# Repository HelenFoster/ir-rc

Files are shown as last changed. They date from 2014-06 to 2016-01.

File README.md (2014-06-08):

Infrared remote control experiments
=====

The aim is to have a tiny transmitter which works with the OpenPandora without compromising on its handheld quality. (For receivers, this is not a problem, because they are generally resting on a solid surface while you send them signals from somewhere else. But for a transmitter, handheld is very useful!)

Currently using very simple descriptions of the waveforms (and two different waveforms per code for the protocols with a toggle bit). Later it would be useful to handle the actual protocols, e.g. integrate with LIRC.

Licensing
----
C code: MIT License (see code headers)
Schematic and PCB files: CC BY-SA http://creativecommons.org/licenses/by-sa/4.0/

rx_dur (Arduino)
----
Monitors a digital signal on the specified pin, waits for this signal to match the trigger level, and outputs a list of comma-separate durations (in microseconds) on Serial. The first duration is the length of time the signal stays at the trigger level; the second is the length of time it stays at the opposite level after that; and so on. It records data until the buffer is full or until the specified maximum time after the trigger, then it transmits on Serial afterwards.

This can be connected to an IR demodulator device to read remote control signals.

tx_tone (Arduino)
----
Reads a comma-separated list of durations (in microseconds) from Serial, and outputs the 38kHz modulated version on the specified pin, using the Arduino tone function. The first duration is the length of the first burst; the second duration is the length of the first space; and so on. The bursts seem to come out about 40us shorter than specified (and the spaces about 40us longer), but the devices I have tested are not fussy about this.

From a handheld perspective, the Uno is too big, and the Nano does not seem to work on the Pandora without a hub.

circuits/led_driver_5V
----
This circuit drives the LED with about 150mA while only drawing a maximum of 23mA from the power supply. It is useful for USB-connected devices like Arduino, on the Pandora's OTG port which can only provide 100mA. The signal output pin from the Arduino is connected to the gate of the MOSFET (signal is active high).

circuits/ftdi_pic_ir
----
This circuit connects an 8-pin PIC with the LED driver and an FTDI Basic Breakout board. (The FT232R bitbang mode looked promising for making the remote control signals itself, but seems to be not sufficiently accurate. So this design uses serial mode with a PIC instead.) The PCB is not tested yet!

tx_pic (PIC12F683)
----
This uses duration-based serial messages like the Arduino projects, but using binary data instead of text to save RAM. The first byte is the carrier period (usually 26); the second byte is a multiplier for burst durations; and the remaining bytes are for the durations not yet multiplied, on-off-on-off-etc (all times in microseconds). The program echoes the serial data received, plus an "ok" or error string.

The buffer is currently 80 bytes long, which is enough for most things. Clearing more space for it would probably involve making the code less readable.

The UART timing is somewhat relying on the time taken by instructions, and might be wrong with a different compiler or compiler settings. I wrote that part first on a less capable PIC. It would be better to use Timer2 instead of Timer0 (and abstract out the delay using the wait_T2 function which is already there).

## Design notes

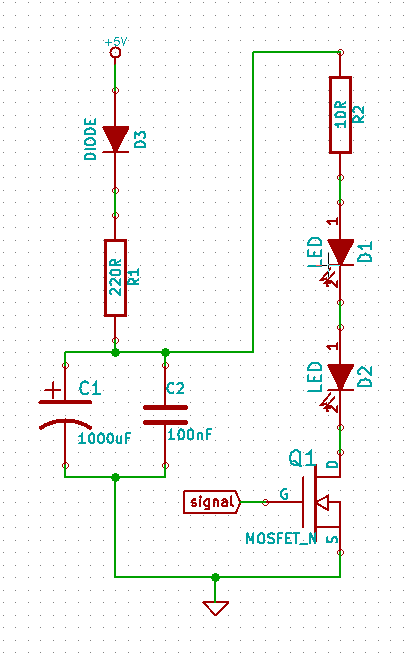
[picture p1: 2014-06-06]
circuits/led_driver_5V.png

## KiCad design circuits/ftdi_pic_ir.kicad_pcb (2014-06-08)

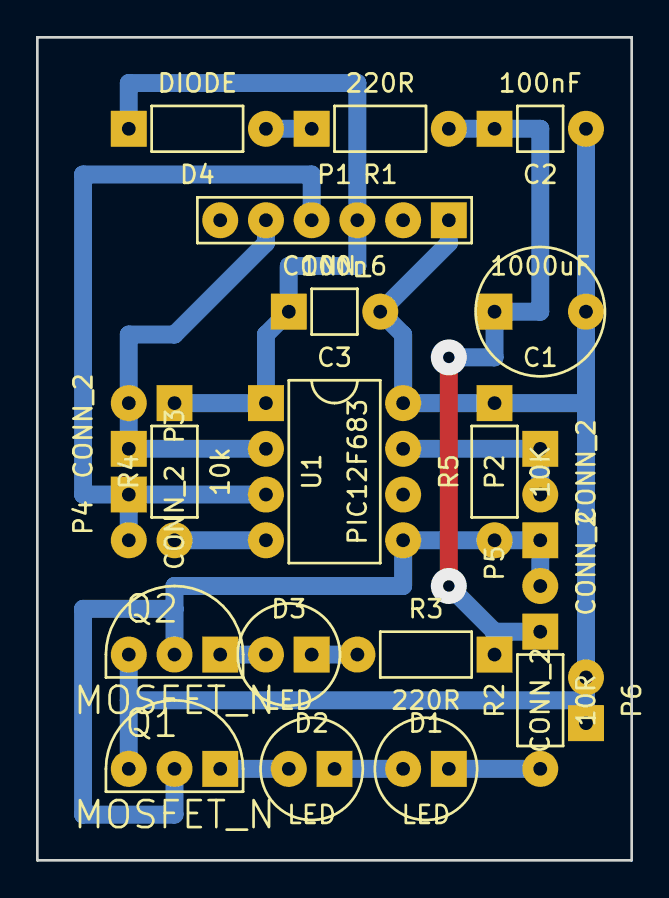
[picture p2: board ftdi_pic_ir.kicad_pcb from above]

Board: 2 copper layers, 33.0 x 45.7 mm, 21 parts (0 on the bottom side), 14 nets.

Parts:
C1: 1000uF; CHUNKY_RADIAL-3
C2: 100nF; CHUNKY_AXIAL-3
C3: 100n; CHUNKY_AXIAL-3
D1, D2, D3: LED; CHUNKY_RADIAL-2
D4: DIODE; CHUNKY_AXIAL-4
P1: CONN_6; CHUNKY_SIL-6
P2, P3, P4, P5, P6: CONN_2; CHUNKY_AXIAL-2
Q1, Q2: MOSFET_N; CHUNKY_2N7000
R1, R3: 220R; CHUNKY_AXIAL-4
R2: 10R; CHUNKY_AXIAL-4
R4: 10k; CHUNKY_AXIAL-4
R5: 10K; CHUNKY_AXIAL-4
U1: PIC12F683; CHUNKY_DIP-8

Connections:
5V: C3.1, D4.1, P1.3, R4.1, U1.1
FTDI_RX__PIC_TX: P1.5, P3.1, P3.2, U1.2
FTDI_TX__PIC_RX: P1.4, P4.1, P4.2, U1.3
GND: C1.2, C2.2, C3.2, P1.1, P6.1, P6.2, Q1.S, Q2.S, R5.1, U1.8
unnamed: D3.1, R3.2
unnamed: P2.1, P2.2, U1.7
unnamed: D3.2, Q2.D
unnamed: D1.1, R2.2
unnamed: D1.2, D2.1
unnamed: D4.2, R1.1
unnamed: R4.2, U1.4
unnamed: D2.2, Q1.D
unnamed: C1.1, C2.1, R1.2, R2.1, R3.1
signal: P5.1, P5.2, Q1.G, Q2.G, R5.2, U1.5

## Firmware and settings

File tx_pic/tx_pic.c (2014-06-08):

/*
Duration-based IR remote control transmission, with PIC serial.
Using PIC12F683 with XC8 compiler.
Accepts binary data via a software UART at 9600 baud. Echoes data + error info.
First byte is carrier period; second byte is multiplier for burst durations;
 remaining bytes for durations on-off-on-etc (all times in microseconds).

Copyright (c) 2014, Helen Foster

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
THE SOFTWARE IS PROVIDED "AS IS", WITHOUT WARRANTY OF ANY KIND, EXPRESS OR
IMPLIED, INCLUDING BUT NOT LIMITED TO THE WARRANTIES OF MERCHANTABILITY,
FITNESS FOR A PARTICULAR PURPOSE AND NONINFRINGEMENT. IN NO EVENT SHALL THE
AUTHORS OR COPYRIGHT HOLDERS BE LIABLE FOR ANY CLAIM, DAMAGES OR OTHER
LIABILITY, WHETHER IN AN ACTION OF CONTRACT, TORT OR OTHERWISE, ARISING FROM,
OUT OF OR IN CONNECTION WITH THE SOFTWARE OR THE USE OR OTHER DEALINGS IN
THE SOFTWARE.
 */

#include <xc.h>
#include <string.h>

// CONFIG
#pragma config FOSC = INTOSCIO  // Internal Oscillator enabled; use pins for IO
#pragma config WDTE = OFF       // Watchdog Timer disabled
#pragma config PWRTE = OFF      // Power-up Timer disabled
#pragma config MCLRE = ON       // MCLR pin enabled
#pragma config CP = OFF         // Code Protection bit disabled
#pragma config CPD = OFF        // Data Code Protection bit disabled
#pragma config BOREN = OFF      // Brown Out Detect disabled
#pragma config IESO = OFF       // Internal External Switchover disabled
#pragma config FCMEN = OFF      // Fail-Safe Clock Monitor disabled

#define UTX_PIN GPIObits.GP5
#define URX_PIN GPIObits.GP4
// IRTX is GP2 for PWM
#define DEBUG_PIN GPIObits.GP0
#define UTX_DELAY 98
#define URX_DELAY 91

#define URX_OK 0
#define URX_ERROR_STOP_BIT 1

#define DATA_OK 0
#define DATA_BAD_FREQ 1
#define DATA_BAD_MUL 2
#define DATA_WARN_FULL 3

//defined here to allow inversion
#define UART_LOW 0
#define UART_HIGH 1

#define BUF_SIZE 80

unsigned char n;
unsigned char buf[BUF_SIZE];

unsigned char T0_ps(unsigned char ps) {
    asm("CLRWDT");
    TMR0 = 0;
    if (ps == 1) {
        OPTION_REGbits.PSA = 1;
    } else {
        OPTION_REGbits.PSA = 0;
        switch(ps) {
            case 2: OPTION_REGbits.PS = 0; break;
            case 4: OPTION_REGbits.PS = 1; break;
            case 8: OPTION_REGbits.PS = 2; break;
            case 16: OPTION_REGbits.PS = 3; break;
            case 32: OPTION_REGbits.PS = 4; break;
            case 64: OPTION_REGbits.PS = 5; break;
            case 128: OPTION_REGbits.PS = 6; break;
            case 0: OPTION_REGbits.PS = 7; break;
            default: return DATA_BAD_MUL;
        }
    }
    return DATA_OK;
}

void wait_T0(unsigned char until) {
    while (TMR0 < until);
    TMR0 = 0;
}

void wait_T2() {
    PIR1bits.TMR2IF = 0;
    while (PIR1bits.TMR2IF == 0);
    PIR1bits.TMR2IF = 0;
}

void uart_tx() {
    unsigned char i, j, c;
    T0_ps(1);
    for (i = 0; i < n; i ++) {
        while (TMR0 < UTX_DELAY);
        UTX_PIN = UART_LOW;
        TMR0 = 0;
        c = buf[i];
        for (j = 0; j < 8; j ++) {
            if (c & 1) {
                while (TMR0 < UTX_DELAY);
                UTX_PIN = UART_HIGH;
                TMR0 = 0;
            } else {
                while (TMR0 < UTX_DELAY);
                UTX_PIN = UART_LOW;
                TMR0 = 0;
            }
            c >>= 1;
        }
        while (TMR0 < UTX_DELAY);
        UTX_PIN = UART_HIGH;
        TMR0 = 0;
    }

}

unsigned char uart_rx() {
    unsigned char c, j, t;
    const unsigned char delay2 = URX_DELAY / 2 + URX_DELAY;
    T0_ps(1);
    n = 0;
    DEBUG_PIN = 1;
    while (URX_PIN == UART_HIGH);
    TMR0 = 0;
    DEBUG_PIN = 0;
    while (n < BUF_SIZE) {
        while (TMR0 < delay2);
        TMR0 = 0;
        c = 0;
        for (j = 0; j < 8; j ++) {
            c >>= 1;
            if (URX_PIN == UART_HIGH) {
                c |= 0x80;
                DEBUG_PIN = 1;
            } else {
                DEBUG_PIN = 0;
            }
            while (TMR0 < URX_DELAY);
            TMR0 = 0;
        }
        if (URX_PIN == UART_LOW) {
            //wrong stop bit
            return URX_ERROR_STOP_BIT;
        }
        buf[n++] = c;
        DEBUG_PIN = 1;
        t = 0;
        while (URX_PIN == UART_HIGH) {
            if (TMR0 >= URX_DELAY) {
                TMR0 = 0;
                t ++;
                if (t >= 20) {
                    return URX_OK;
                }
            }
        }
        TMR0 = 0;
        DEBUG_PIN = 0;
    }
    return URX_OK;
}

unsigned char ir_tx() {
    unsigned char c, i, r, lv;
    
    //setup PWM
    TRISIObits.TRISIO2 = 1;
    PR2 = buf[0];
    CCP1CONbits.CCP1M = 0b1110; //PWM active low
    CCPR1L = buf[0] >> 1; CCP1CONbits.DC1B = 0;
    PIR1bits.TMR2IF = 0; //clear interrupt
    T2CONbits.T2CKPS = 0; //1:1 prescaler
    T2CONbits.TMR2ON = 1;

    r = T0_ps(buf[1]);
    if (r != DATA_OK) {
        return r;
    }

    DEBUG_PIN = 1;
    lv = 1;
    wait_T0(0);
    wait_T2();
    for (i = 2; i < n; i ++) {
        DEBUG_PIN = lv;
        if (lv) {
            TRISIObits.TRISIO2 = 0;
        } else {
            TRISIObits.TRISIO2 = 1;
        }
        lv = 1 - lv;
        c = buf[i];
        wait_T0(c);
        wait_T2();
    }
    DEBUG_PIN = 0;
    TRISIObits.TRISIO2 = 1;
    if (n == BUF_SIZE) {
        return DATA_WARN_FULL;
    } else {
        return DATA_OK;
    }
}

void uart_tx_str(const char *s) {
    strcpy(buf, s);
    n = strlen(s);
    uart_tx();
}

void main(void) {
    unsigned char r;
    ANSEL = 0;
    WPUbits.WPU2 = 0;
    OPTION_REGbits.nGPPU = 0;
    OPTION_REGbits.T0CS = 0; //timer0 internal clock
    TRISIObits.TRISIO5 = 0; //GP5 output
    TRISIObits.TRISIO0 = 0;
    DEBUG_PIN = 0;

    //test ir_tx and uart_tx for when not connected to real uart
    buf[0] = 25;
    buf[1] = 32;
    buf[2] = 10;
    buf[3] = 20;
    buf[4] = 10;
    n = 5;
    ir_tx();
    uart_tx();
    T0_ps(0);
    wait_T0(255);
    
    while (1) {
        r = uart_rx();
        if (r == URX_OK) {
            r = ir_tx();
            uart_tx();
            if (r == DATA_OK) {
                uart_tx_str(" ok\n");
            } else if (r == DATA_WARN_FULL) {
                uart_tx_str(" full\n");
            } else {
                uart_tx_str(" unknown error\n");
            }
        } else {
            uart_tx();
            uart_tx_str(" UART RX error\n");
        }
    }
    return;
}

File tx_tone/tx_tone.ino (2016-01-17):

/*
Reads a comma-separated list of durations (in microseconds) from Serial,
and outputs the 38kHz modulated version on the specified pin.

If SPECIAL_PWM is defined, uses timer1 PWM on Arduino pin 10
(intended for SparkFun Pro Micro, but should work on other ATmega32U4 boards, 
and also ATmega328 which has the same timer1 settings).
Otherwise uses the Arduino tone function, as in previous versions.

Copyright (c) 2014, Helen Foster

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
THE SOFTWARE IS PROVIDED "AS IS", WITHOUT WARRANTY OF ANY KIND, EXPRESS OR
IMPLIED, INCLUDING BUT NOT LIMITED TO THE WARRANTIES OF MERCHANTABILITY,
FITNESS FOR A PARTICULAR PURPOSE AND NONINFRINGEMENT. IN NO EVENT SHALL THE
AUTHORS OR COPYRIGHT HOLDERS BE LIABLE FOR ANY CLAIM, DAMAGES OR OTHER
LIABILITY, WHETHER IN AN ACTION OF CONTRACT, TORT OR OTHERWISE, ARISING FROM,
OUT OF OR IN CONNECTION WITH THE SOFTWARE OR THE USE OR OTHER DEALINGS IN
THE SOFTWARE.
*/

#define SPECIAL_PWM
const int irLedPin = 10; //should be 10 for special PWM

const int visibleLedPin = 17;
const int visibleLedOn = LOW;
const int visibleLedOff = HIGH;

const int bufSize = 200;

unsigned long buffer[bufSize];
int items;

void setup() {
    Serial.begin(9600);
    while (!Serial);
    Serial.setTimeout(200);
    pinMode(visibleLedPin, OUTPUT);
    pinMode(irLedPin, OUTPUT);

#ifdef SPECIAL_PWM
    //fast PWM with period OCR1A: WGM13:0 = 15
    //no clock prescaler (16MHz clock): CS12:0 = 1
    TCCR1A = _BV(WGM11) | _BV(WGM10);
    TCCR1B = _BV(WGM13) | _BV(WGM12)   | _BV(CS10);
    OCR1A = 421; //for 38Khz
    OCR1B = 100; //cycles it's on for
#endif
}

void startBurst() {
    digitalWrite(visibleLedPin, visibleLedOn);
#ifdef SPECIAL_PWM
    //output B non-inverting: COM1B1:0 = 2
    TCCR1A |= _BV(COM1B1);
#else
    tone(irLedPin, 38000);
#endif
}

void stopBurst() {
    digitalWrite(visibleLedPin, visibleLedOff);
#ifdef SPECIAL_PWM
    //turn off PWM output
    TCCR1A &= ~_BV(COM1B1);
#else
    noTone(irLedPin);
#endif
}

void loop() {
    int i = 0;
    byte level = 1;
    unsigned long time, prevTime;
    if (Serial.available()) {
        long data;
        while (data = Serial.parseInt()) {
            if (i < bufSize) {
                buffer[i++] = data;
            }
        }
        items = i;
        Serial.print("received ");
        Serial.println(items);
        prevTime = micros();
        for (i = 0; i < items; i ++) {
            unsigned long us = buffer[i];
            if (level) {
                startBurst();
            } else {
                stopBurst();
            }
            while ((time=micros()) - prevTime < us);
            prevTime = time;
            level = !level;
        }
    }
    stopBurst();
}

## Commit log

2014-05-31 Added previous Arduino projects.
2014-05-31 Added LED circuit
    [led_driver_5V.kicad.sch]
2014-06-06 Modified LED driver circuit
    [led_driver_5V.kicad.sch]
2014-06-06 Working on PCB for PIC circuit
    [ftdi_pic_ir.kicad.sch, ftdi_pic_ir.kicad_pcb]
2014-06-08 Added ground clip to PIC circuit
    [ftdi_pic_ir.kicad.sch, ftdi_pic_ir.kicad_pcb]
2014-06-08 Moved a track on PIC circuit
    [ftdi_pic_ir.kicad_pcb]
2015-11-20 Arduino receiver: reduced precision to store more values
2016-01-17 Arduino transmitter: real PWM option, so we can vary the duty cycle
